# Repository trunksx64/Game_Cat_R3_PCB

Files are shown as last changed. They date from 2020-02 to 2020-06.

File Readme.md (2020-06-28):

# Game//Cat ::: Revsion_R3 :: Versión 2.91



## Razon de Ser e Inspiración

Este Control se basa en la Idea Original del Game//Cat Version R1, el cual asu vez se inspira en el diseño del joystick y botones del Arduino Esplora. El primer Control se implemento para ser usado como parametrizador y las siguientes revsiones se presento como Tesis de Grado de Especialización de Instrumentación Industrial que curse. Se Utilizo principalmente como Herramienta de Programacion para Tarjeta de Control de Ascensores Usando Un Firmware de Codigo Cerrado. Se Implemento FREERTOS para su uso, asi como librerias Basicas en MplabX y XC16. La idea principal es usar los Microcontroladores de 16Bits de Microchip con perifericos listos y configurados. Es pequeño y Portable, ideal para llevar a todo lado, no intenta competir con controles similares a Arduino. Se desea implentar a futuro un Bootloader tanto por USB, RS232, SD y CAN.

Por el Momento Requiere Programdor Basado en Pickit2 como minimo o un ICD3. Link

## Caracteristicas del Hardware

  * Microcontrolador PIC24HJ128GP504.
  * Pantalla LCD PCD8544 (Based Nokia GLCD) - SPI.
  * Joystick Análogo de 2 ejes + Botón Digital.
  * 4 Botones Digitales.
  * Accelerometro - MMA8452Q - I2C. 
  * Sensor de Temperatura (LM61).
  * Sensor de Luz (LDR).
  * Memoria Eeprom 24LCXXX - I2C.
  * Memoria Ram 23KXX - SPI.
  * Ranura Memoria Micro-SD - SPI.
  * Buzzer por PWM.
  * Conexión USB - FTDI-RL232/UART - 5V.
  * Conexión CAN 5V.
  * 2 LED´s de Actividad.
  * Salidas Para PWM y UART - Configurables - 3V.
  * Conexión ICSP con linea AUX, para control extra de puerto.
  * Cargador de Bateria Lipo (MCP73831) con Indicador LED.

## Caracteristicas Espesificas

  * Debido a que el PIC trabaja a 3.3V, el uso del MCP2551 y el FTDI-RL232 esta a 5V, alimentado directamente por el Control USB, el FTDI-RL232 se encarga de "gestionar" la alimentación del sistema proporcionando un arranque suave en la tensión, luego se pasa por un regulador de 3,3V para alimentar el resto de componentes.
  * Para Potabilidad he agregado un control para la carga de Baterías de tipo Lipo, este gobernado el con el CI MCP73831, el cual mediante el uso del Mosfet DMP1045, intercambia la alimentación proveniente del FTDI-RL232 y la Batería según el estado de conexión USB, se puede usar Baterías de 3,7V en adelante hasta un máximo de 6V, cuando el Game//Cat esta usando la Batería, el FTDI-RL232 se deshabilita.
  * Para el Manejo del Joystick, Botones, Sensor de Temperatura y Luz. he usado el CI-74HC4051, que es un Multiplexor Análogo para leer los Valores por el Modulo ADC, el cual puede usarse de 10 o 12Bits en conjunto con un canal DMA si fuere necesario.
  * La Comunicación UART, es una Salida/Entrada dedicada con un conversor de tensión de 3.3V a 5V de forma bidireccional con trasnsitores Mosfet, con el fin de proteger y poder comunicar el PIC24H con cualquier tipo de dispositivo.
  * La Comunicación USB se hace por medio del CI FTDI-RL232, esto es porque el PIC no posee dicho Modulo y ademas permite ahorrar en la Memoria del PIC el Stack del USB, esto permite que sea Conectar y Usar, puesto que los Drives de este USB son reconocidos de forma inmediata por Windows y Linux sin problemas.
  * La Comunicación CAN la he Incluido porque en estos momentos trabajo con esta interface y su popularidad ha crecido bastante, por experiencia este BUS es muy robusto y fácil de usar, en el PIC se hace uso de dos canales DMA teniendo una respuesta bastante rápida y sin sacrificar la memoria RAM principal, su conexión se hace por medio del Transeiver MCP2551, ademas he agregado un par de diodos TVH para proteger dicho CI.
  * La Ranura para la Tarjeta Micro-SD, posee conexión Modulo SPI la cual esta compartida con la Memoria Ram 23Kxxx, Ademas la pantalla posee también una conexión al segundo Modulo SPI, que puede usarse para "colgar" otros dispositivos si no vamos ha usar la Pantalla.
  * El control del Buzzer se ha dejado por un Pin que puede ser usado tanto por el Modulo PWM o un pin Común, su uso dependerá del Programa o Aplicación.
  * Posee una Memoria I2C en conjunto con un Accelerometro, con comunicación directa.
  * La programación se hace por medio de la conexión ICSP o Bootloader por USB, usando cualquier programador, PICKIT2-3 y/ó ICD2-3, igual estas salidas pueden usarse como cualquier puerto, teniendo presente que no poseen ninguna protección a tensiones superiores de 3,3V.
  * Ya por Ultimo, he dejado dos visualizadores, que son libres de uso.

Básicamente esto es el GAME//CAT, una tarjeta mas que un sistema de control para usuarios avanzados, es una tarjeta de entrenamiento para los principiantes, puesto que todo lo que incluye hace uso forzoso de todo los controles que el PIC24HJ128GP504 incorpora.

## Microcontrolador

* Architecture 16-bit.
* CPU Speed Max. 40 MIPS.
* Memory Type Flash.
* Program Memory 128Kb.
* RAM 8,192 Bytes.
* Temperature Range C -40 to 150.
* Operating Voltage Range (V) 3 to 3.6.
* I/O Pins 35 & Pin Count    44.
* Internal Oscillator 7.37 MHz, 32.768 kH.
* Digital Communication Peripherals 2-UART, 2-SPI,1-I2C, 1-CAN.
* Comparators 2, Capture/Compare/PWM Peripherals 4/4, PWM Resolution bits 16.
* Timers 5 x 16-bit 2 x 32-bit.
* Parallel Port PMP(No Usado), Hardware RTCC-1 (No Usado).
* Chanel DMA-8.
* Cap Touch Channels-13 (No Usado).

## Versiones

* 2017 : 1.0.0 : Primera Version en Kicad 4
* 2017 : 1.2.0 : Se Agrego Conversion de Tension 5V a 3.3V Bidirecional en salida UART y PWM, se elimino conexion DC externa.
* 2018 : 2.0.0 : Se Migro completamente a Kicad 5, el Led control se removio para dar opcion de seleccion de Periferico SPI (Ram y SD).
* 2018 : 2.1.0 : Se rediseño y corrigio error en boton del Joystick, se corrigio el trucado de lineas de Programacion PGM y PGD.
* 2018 : 2.2.0 : Se Agrego Resistencias de proteccion (0Ohm) en entradas Jack RJ11 de Programacion.
* 2018 : 2.1.0 : Se Agrego y Calibro Resistencia del Boton de Reset, se agrego control se Carga para Bateria Lipo 3.3V.
* 2018 : 2.5.0 : Se Actulizaron Logos de la Marca y de Hardware Libre, se Actulizo a licencia Creative Commons V4.
* 2018 : 2.7.0 : Se Actulizaron las Librerias de Modulos de Kicad, basadas en Progetti.
* 2018 : 2.9.0 : Se Agregaron condensadores de filtrado al multiplexor analogo, se cambiaron los botones por diseño con poste.
* 2019 : 2.9.1 : Se Organizaron los Archivos para Hospedarlos en Github, Se Ordenaron condensandores y Cristal del PIC.

## Creditos

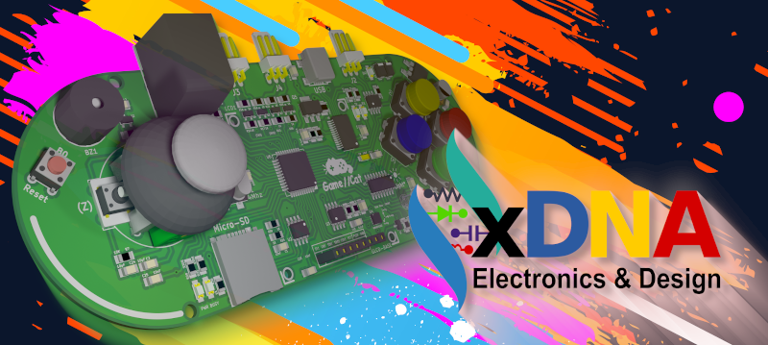
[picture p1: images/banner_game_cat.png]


xDNA Electronics & Desing es una Micro-empresa Personal, que se dedica y encarga de elaborar proyectos de Control y Automatización por pedido, su idea es colaborar y ayudar a quines a si lo requieran, el proyecto se hizo principalmente como Hobby el cual gracias a terceros se pudo implementar y hacer su creación, por lo cual se da la libertad de usarlo para experimentar sin hacer uso comercial del mismo.

## Licencia

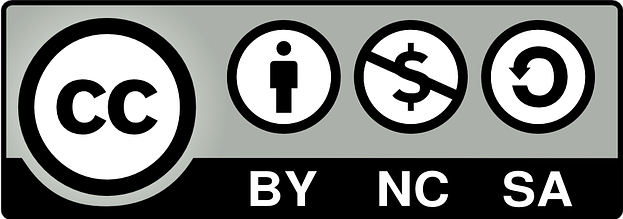
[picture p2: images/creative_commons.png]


Licensed under Attribution-NonCommercial-ShareAlike 4.0 International (CC BY-NC-SA 4.0)

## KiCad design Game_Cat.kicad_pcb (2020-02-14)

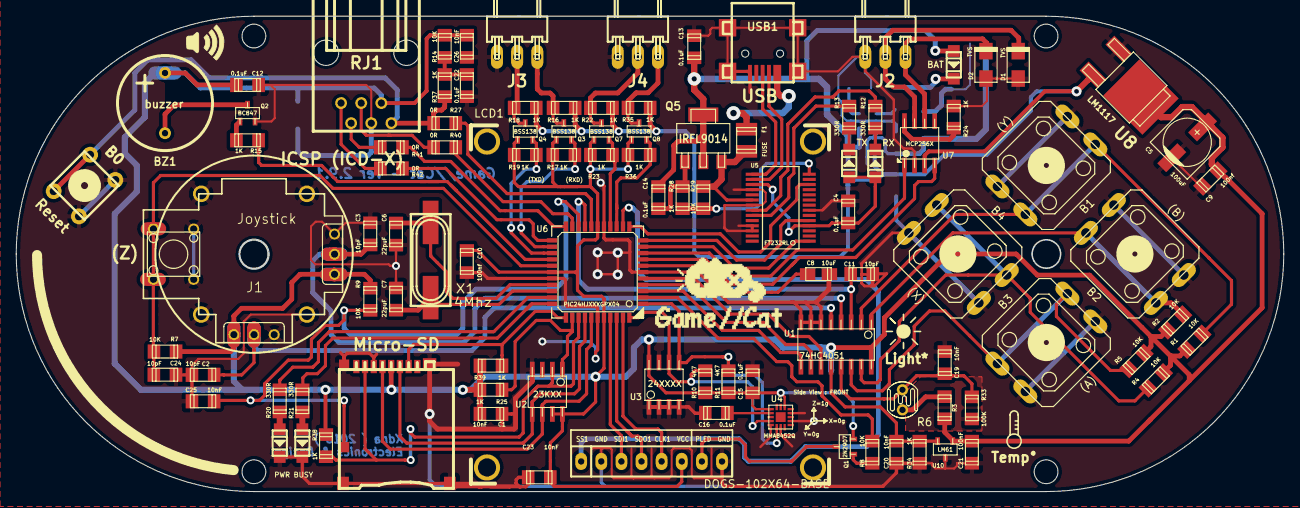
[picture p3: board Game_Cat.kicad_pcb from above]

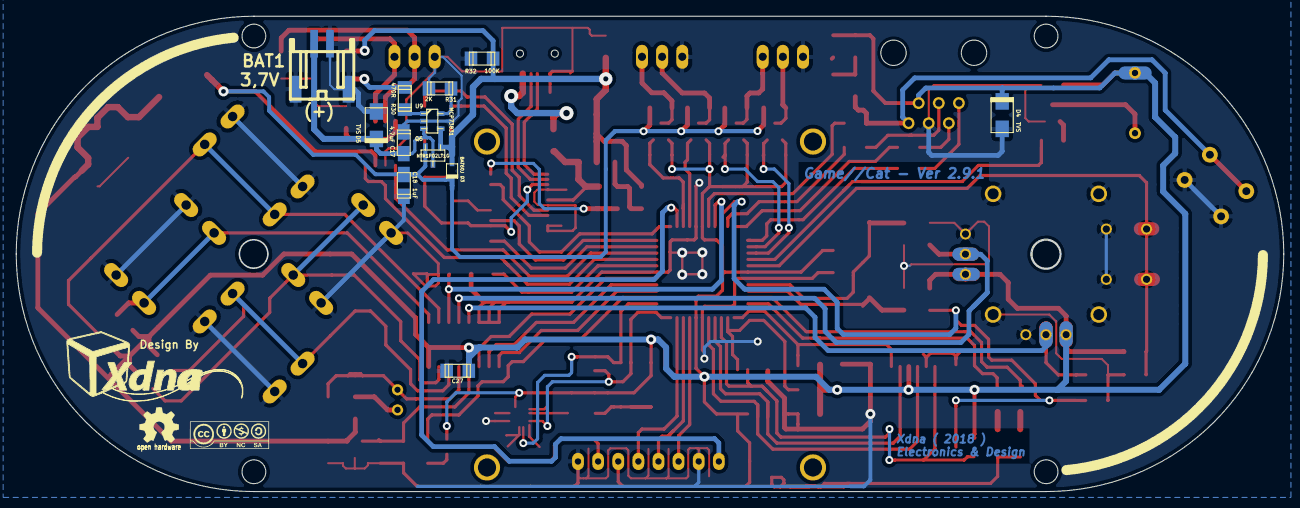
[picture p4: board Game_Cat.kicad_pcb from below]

Board: 2 copper layers, 160.0 x 60.0 mm, 113 parts (12 on the bottom side), 84 nets.

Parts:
B0: Reset; PCB_PUSH
B1: (Y); tactil-swicht-post-yellow-12x12
B2: (B); tactil-swicht-post-red-12x12
B3: (A); tactil-swicht-post-green-12x12
B4: (X); tactil-swicht-post-blue-12x12
BAT1: 3,7V; s2b-ph-sm4-tb
BZ1: buzzer; buzzer_tmb
C1, C19, C20, C23, C25, C26: 10nF; c_1206
C2, C3, C11, C24: 10pF; c_1206
C4, C12, C13, C14, C15, C16, C22: 0.1uF; c_1206
C5: 100uF; c_elec_6.3x4.5
C6, C7: 22puF; c_1206
C8: 10uF; c_tant_S
C9, C10: 100nf; c_1206
C17: 4,7uF; c_tant_A
C18: 1uF; c_tant_A
C21: 100nF; c_1206
C27: 1uF; c_1206
D1, D2, D4, D5: TVS; do214ac
D3: BAT60J; sod323
F1: FUSE; r_1210
J1: Joystick; joystick
J2: CAN; molex-7593-3
J3: UART; molex-7593-3
J4: PWM; molex-7593-3
LCD1: DOGS-102X64-BASE; lcd-dogs-102x64-base
LD1: RX; Led_1206
LD2: TX; Led_1206
LD3: PWR; Led_1206
LD4: BUSY; Led_1206
LD5: BAT; Led_1206
Q1: 2N2907; sot23
Q2: BC847; sot23
Q3, Q4, Q7, Q8: BSS138; sot23
Q5: IRFL9014; sot223
Q6: NTR1P02LT1G; sot23
R1, R2, R3, R4, R5, R7, R8, R9, R14, R29: 10K; r_1206
R6: LDR; photo-cell
R10, R11: 4K7; r_1206
R12, R13, R20, R21: 330R; r_1206
R15, R16, R17, R18, R19, R22, R23, R24, R25, R28, R34, R35, R36, R37, R38, R39: 1K; r_1206
R27, R40, R41, R42: 0R; r_1206
R30: 470R; r_1206
R31: 2K; r_1206
R32, R33: 100K; r_1206
RJ1: ICSP (ICD-X); molex_6p6c
SD1: Micro-SD; micro-sd-socket
U1: 74HC4051; so-16
U2: 23KXX; so-8
U3: 24XXXX; so-8
U4: MMA8452Q; qfn-16
U5: FT232RL; ssop-28
U6: PIC24HJXXXGPX04; lqfp44
U7: MCP256X; psop-8
U8: LM1117; d-pak
U9: MCP73831; sot23-5
U10: LM61; sot23
USB1: USB; conn_usb_B_mini_smd
X1: 4Mhz; hc-49_smd

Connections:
+3V3: BZ1.1, C1.1, C5.1, C9.1, C10.1, C12.1, C15.1, C21.1, C23.1, C26.1, C27.2, D4.2, J1.1, J1.4, LCD1.6, Q1.3, Q3.1, Q4.1, Q7.1, Q8.1, R1.1, R2.1, R3.1, R4.1, R5.1, R7.2, R9.2, R10.1, R11.1, R14.1, R17.1, R19.1, R23.1, R25.2, R36.1, R38.2, R39.2, RJ1.2, SD1.4, U1.16, U2.7, U2.8, U3.8, U4.1, U4.14, U6.17, U6.28, U6.40, U8.2, U10.1
+5C: C18.1, D3.2, Q6.3, R16.1, R18.1, R22.1, R35.1, U7.3, U8.3
/B(A): B3.1, B3.2, R5.2, U1.14
/B(B): B2.1, B2.2, R2.2, U1.1
/B(X): B4.1, B4.2, R4.2, U1.15
/B(Y): B1.1, B1.2, R1.2, U1.2
/BAT: BAT1.1, C17.1, D5.2, Q6.2, U9.3
/CANH: D1.2, J2.2, U7.7
/CANL: D2.2, J2.1, U7.6
/CBUS0: R13.2, U5.23
/CBUS1: R12.2, U5.22
/CTRL: BZ1.2, Q2.2
/LED: LCD1.7, Q1.2
/PROG: R31.2, U9.5
/RESET_: R27.1, U6.18
/RS: R24.1, U7.8
/USBDM: U5.16, USB1.2
/USBDP: U5.15, USB1.3
/VCAP: C8.1, U6.7
/_AUX: R42.1, RJ1.6
/_PGC: R41.1, RJ1.5
/_PGD: R40.1, RJ1.4
ADC-0: C11.2, U1.3, U6.19
AUX: R42.2, U6.23
AXIS(X): C2.1, J1.2, U1.5
AXIS(Y): C3.1, J1.5, U1.4
BUTTON-R: C24.1, J1.7, R7.1, U6.27
BUZZER: R15.1, U6.26
CHECK-SD: C25.1, R9.1, SD1.CD2, U6.20
CLK1: LCD1.5, U6.43
CLK2: SD1.5, U2.6, U6.38
CTRL-LED: R8.2, U6.2
GND: B0.1, B0.3, B1.3, B1.4, B2.3, B2.4, B3.3, B3.4, B4.3, B4.4, BAT1.2, C1.2, C2.2, C3.2, C4.2, C5.2, C6.2, C7.2, C8.2, C9.2, C10.2, C11.1, C12.2, C13.2, C15.2, C16.2, C17.2, C18.2, C19.2, C20.2, C21.2, C22.2, C23.2, C24.2, C25.2, C26.2, C27.1, D1.1, D2.1, D4.1, D5.1, J1.3, J1.6, J1.8, J1.9, J2.3, J3.3, J4.3, LCD1.2, LCD1.8, LD3.2, LD4.2, Q2.3, R24.2, R31.1, R32.1, R33.2, R34.2, RJ1.3, SD1.6, SD1.CD1, U1.6, U1.7, U1.8, U2.4, U3.1, U3.2, U3.3, U3.4, U3.7, U4.5, U4.7, U4.10, U4.12, U5.7, U5.18, U5.21, U5.25, U5.26, U6.6, U6.16, U6.29, U6.39, U7.2, U8.1, U9.2, U10.2, USB1.5
LED-BUSY: R21.2, U6.33
LED-PW: R20.2, U6.32
LIGHT: C19.1, R6.2, R33.1, U1.13
LV: C4.1, LD1.1, LD2.1, U5.4, U5.17
MUX-A: U1.11, U6.5
MUX-B: U1.10, U6.4
MUX-C: U1.9, U6.3
unnamed: C13.1, C14.2, D3.1, LD5.1, Q5.2, Q6.1, R32.2, U9.4
unnamed: C14.1, Q5.1, R28.2
unnamed: C16.1, U4.2
unnamed: C22.1, R14.2, R37.1
unnamed: F1.1, USB1.1
unnamed: LD1.2, R12.1
unnamed: LD2.2, R13.1
unnamed: LD3.1, R20.1
unnamed: LD4.1, R21.1
unnamed: LD5.2, R30.1
unnamed: Q1.1, R8.1
unnamed: Q2.1, R15.2
unnamed: R3.2, R6.1
unnamed: R30.2, U9.1
OSC1: C6.1, U6.30, X1.1
OSC2: C7.1, U6.31, X1.2
PGC: R41.2, U6.22
PGD: R40.2, U6.21
PWMA-3V3: Q7.3, R23.2, U6.15
PWMA-5V: J4.2, Q7.2, R22.2
PWMB-3V3: Q8.3, R36.2, U6.14
PWMB-5V: J4.1, Q8.2, R35.2
PWREN: R28.1, R29.2, U5.14
RESET: B0.2, B0.4, R27.2, R37.2, RJ1.1
RXC: U6.8, U7.4
RXD: U5.5, U6.11
RXU-3V3: Q4.3, R19.2, U6.25
RXU-5V: J3.2, Q4.2, R18.2
SCL: R10.2, U3.6, U4.4, U6.44
SDA: R11.2, U3.5, U4.6, U6.1
SDI1: LCD1.3, U6.41
SDI2: R38.1, SD1.7, U2.2, U6.36
SDO1: LCD1.4, U6.42
SDO2: SD1.3, U2.5, U6.37
SLEEP: U5.12, U6.12
SS1: LCD1.1, U6.13
SS_RAM: R25.1, U2.1, U6.35
SS_SD: R39.1, SD1.2, U6.34
TEMP: C20.1, R34.1, U1.12, U10.3
TXC: U6.9, U7.1
TXD: U5.1, U6.10
TXU-3V3: Q3.3, R17.2, U6.24
TXU-5V: J3.1, Q3.2, R16.2
VCC+: F1.2, Q5.3, R29.1, U5.19, U5.20
